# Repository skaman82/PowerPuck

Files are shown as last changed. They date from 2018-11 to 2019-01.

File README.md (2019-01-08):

# PowerPuck
I started this project because I was tired of my fatshark beeping and shutting down at 3.6 volts. I am using a 2s 18650 3500mAh pack. This means my batteries are still almost half full when this happens. I first just used a 9v stepup to boost the voltage, but then tracking the battery level was a pain. Then I came up with this solution. 

It not only lets you use your 18650 batteries up to 3v (per cell), it also adds voltage monitoring with adjustable alarms and a power on/off switch. On top of that the fan cable is now tidy and nice and the complete unit remains on the goggles the whole time while the battery is sitting in the pocket or on the belt.

The battery case has also a basic battery indicator - it gives a pretty good orientation of the battery state without hooking the battery up. 

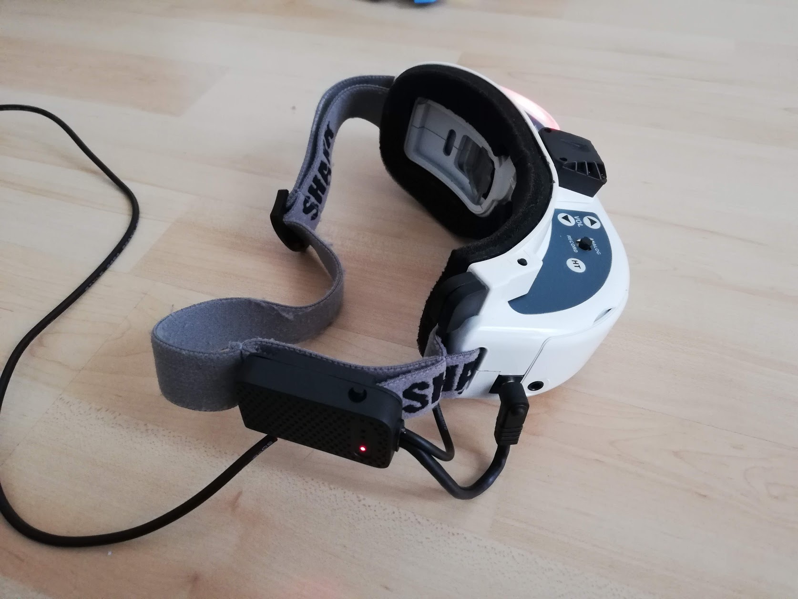
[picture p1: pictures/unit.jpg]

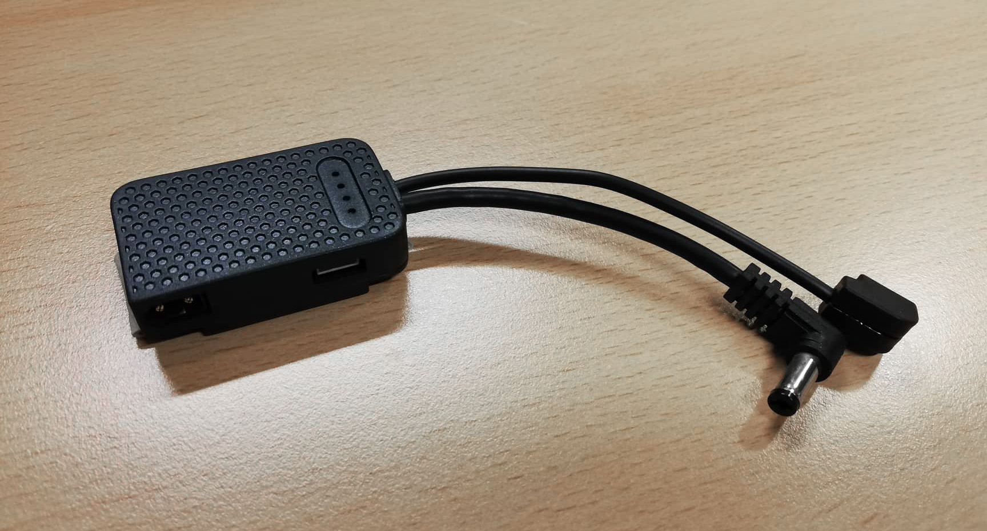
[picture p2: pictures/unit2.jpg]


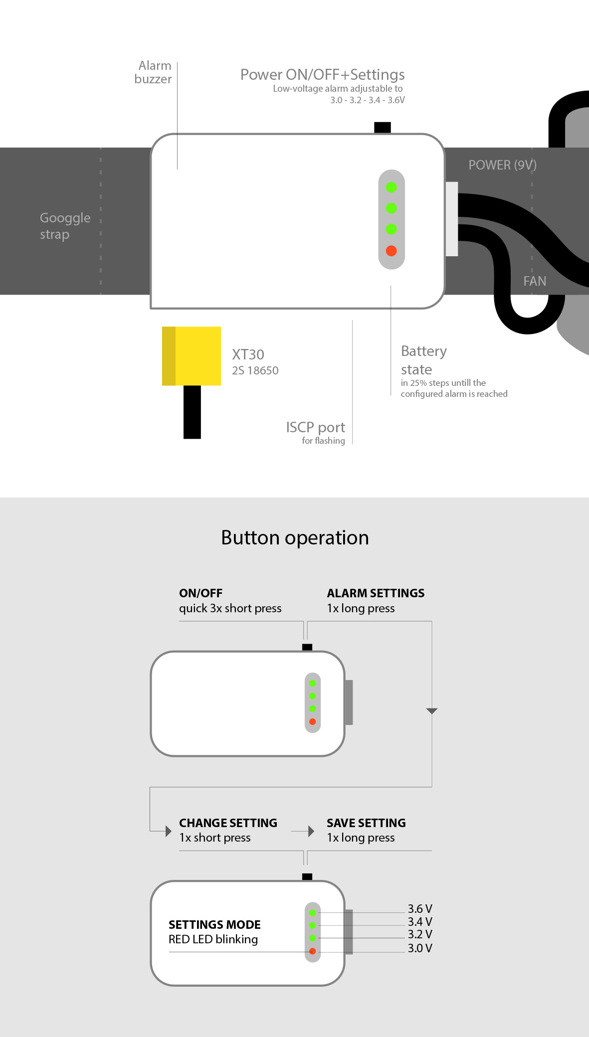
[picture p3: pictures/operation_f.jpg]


# MAIN UNIT COMPONENTS
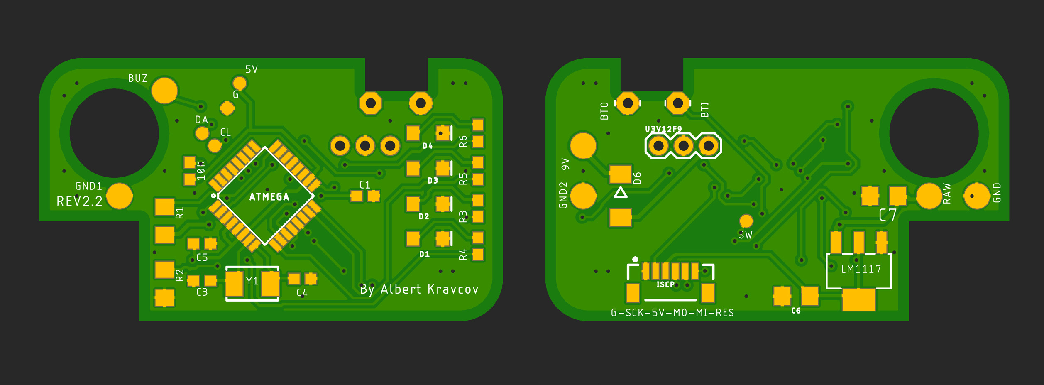
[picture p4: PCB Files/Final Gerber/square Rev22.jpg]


<b>Printed Case</b></br>
See 3D files directory</br>
or order it here:</br>
https://www.shapeways.com/product/Y7TP35MAT/powerpuck-case-front</br>
https://www.shapeways.com/product/XVMKZEAJ4/powerpuck-case-back</br>
</br></br>

<b>Order the PCB on jlcpcb.com (1mm thickness)</b></br>
See "PCB Files > Final Gerber" directory</br></br>

<b>ATMEGA382 AU</b></br>
<b>Y1: Xtal 16MHZ TXC 7A-16.000MAAJ-T</b></br>
<b>C1: 0,1uF cap 0603</b></br>
<b>C5: 100nF cap 0603</b></br>
<b>C3, C4: 18pF cap 0603 (2x)</b></br>
<b>10K 0603 Resistor</b></br>
<b>R3-R6: 330Ohm 0603 Resistor (4x)</b></br>
<b>D2-D4: GREEN LED 1206 (3x)</b></br>
<b>D1: 1x RED LED 1206</b></br>
<b>R1: 18K Resistor 1206</b></br>
<b>R2: 4,7K Resistor 1206</b></br>
<b>C6, C7: 10uF Cap 1206 (2x)</b></br>
<b>D6: Diode S1A</b></br>
<b>Pololu 9V Step-Up Voltage Regulator U3V12F9</b></br>
<b>Pololu Mini Pushbutton Power Switch SV</b></br>
<b>JST-SH Socket 6pin</b></br>
<b>9mm active Buzzer</b></br>
<b>8mm tact button</b></br>
<b>AMASS XT30 female plug</b></br>
<b>AMS1117/LM1117 regulator</b></br>
<b>Epoxy</b></br></br>

<b>ISCP USB Programmer like</b></br>
https://de.aliexpress.com/item/5-v-Micro-USB-Tiny-AVR-ISP-ATtiny44-USBTinyISP-Programmierer-Modul-F-r-Bootloader-ISP-Mikrocontroller/32925343387.html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</br></br>

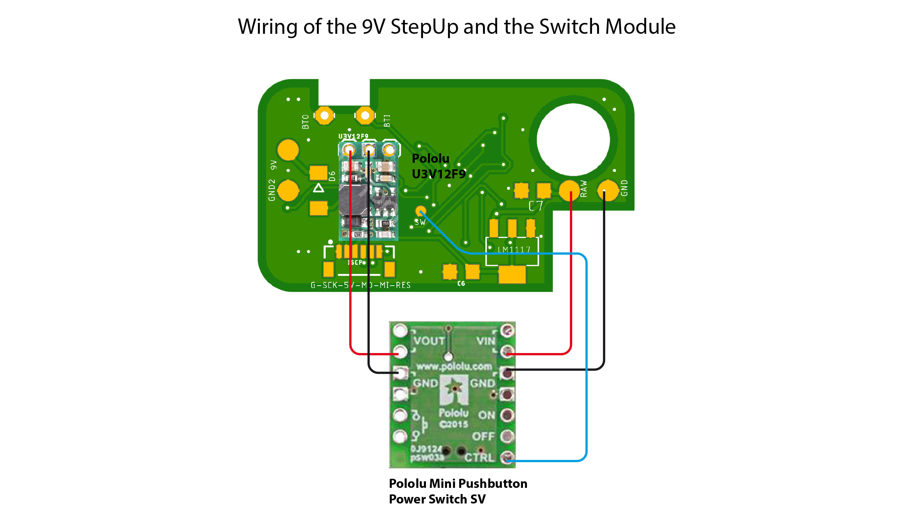
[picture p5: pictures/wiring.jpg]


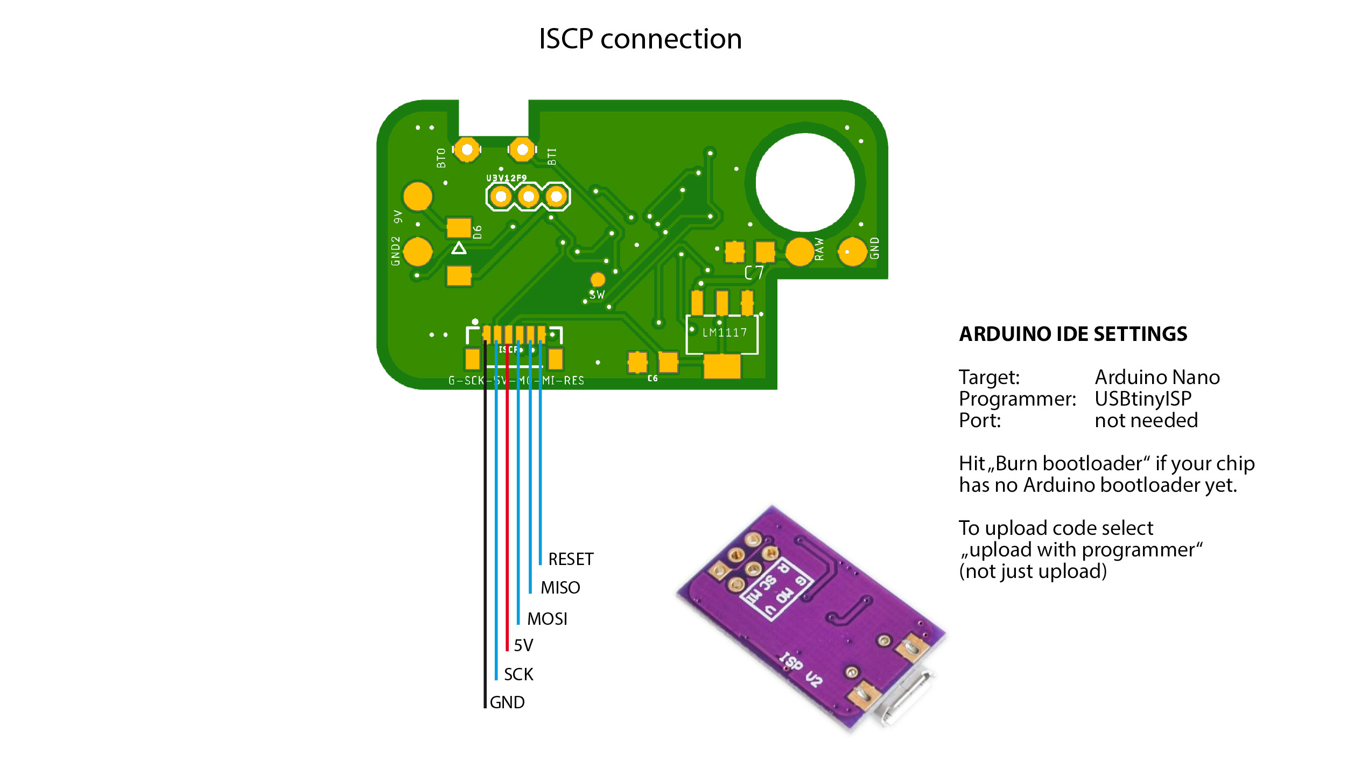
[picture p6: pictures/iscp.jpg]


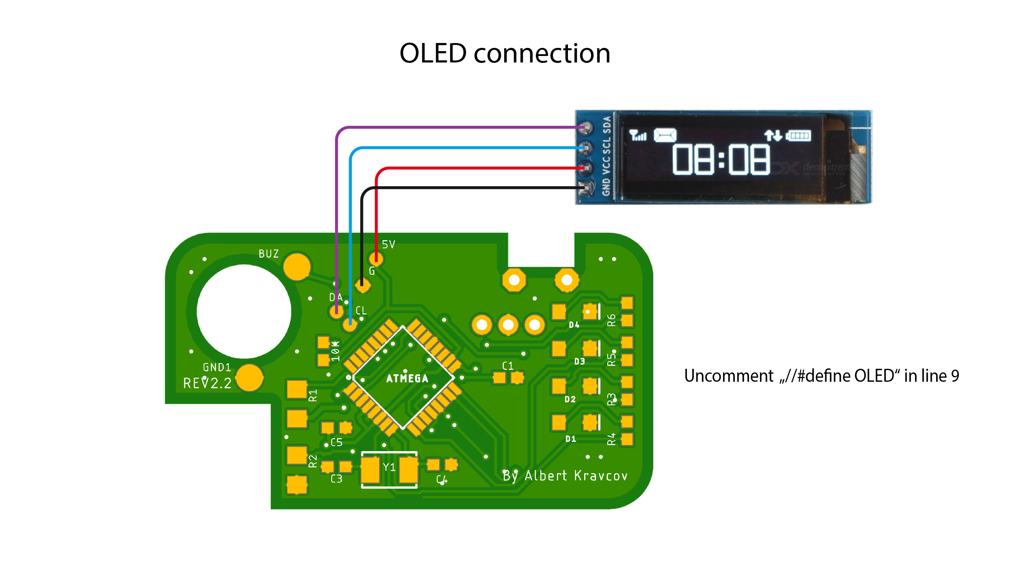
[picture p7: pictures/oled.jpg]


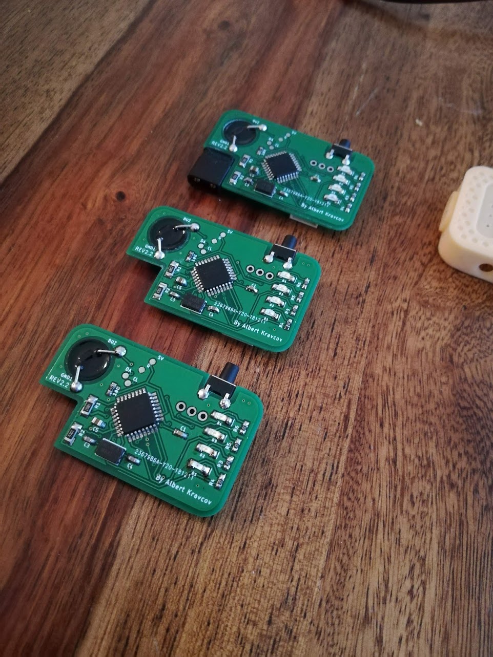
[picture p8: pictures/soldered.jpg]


# 18650 CASE COMPONENTS
<b>Printed Case</b></br>
See 3D files directory</br></br>

<b>2S Power-Indicator</b></br>
https://www.banggood.com/2S-3S-4S-5S-Lipo-Battery-Voltage-Display-Indicator-Board-Polymer-Power-Indicator-Panel-p-1095698.html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</br></br>

<b>2S BMS PCB</b></br>
https://www.aliexpress.com/item/2S-7-4V-8-4V-8A-16A-18650-Lithium-Battery-Protection-Board-Current-Li-ion-2/32851804815.html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</br></br>

<b>XT30 connectors</b></br>
https://www.banggood.com/de/Tarot-RC-Helicopter-Part-Amass-One-Pair-XT30-Non-slip-Plugs-TL2918-p-954269.html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</br></br>

<b>2S Balance plug</b></br>
https://www.banggood.com/de/Lipo-Battery-Balance-Charging-Extension-Wire-Cable-20cm-2S-3S-4S-6S-p-951866.html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
</br>
<b>Epoxy</b></br></br>

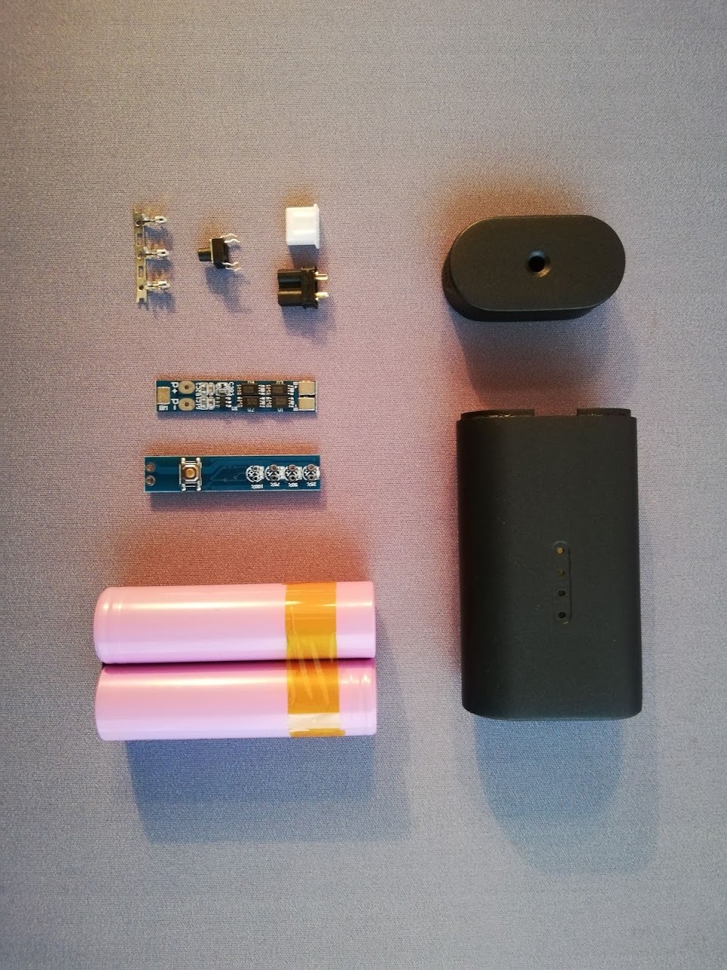
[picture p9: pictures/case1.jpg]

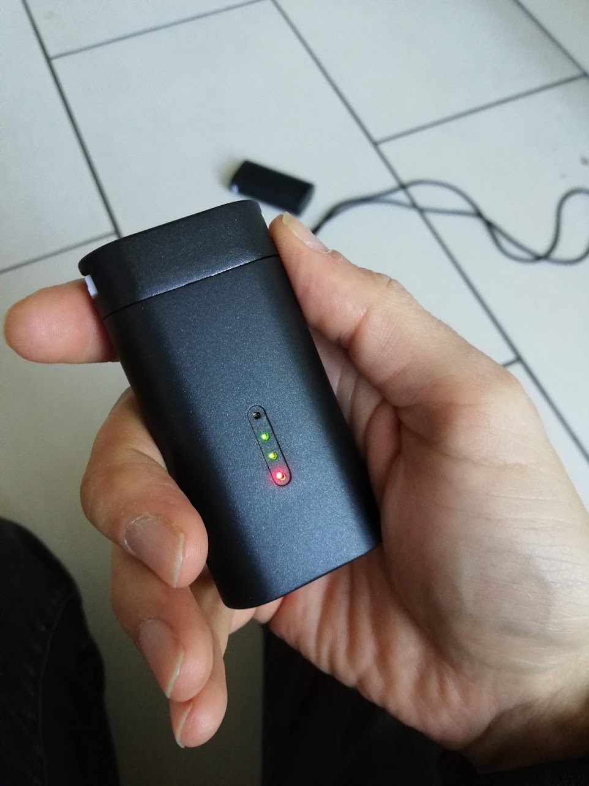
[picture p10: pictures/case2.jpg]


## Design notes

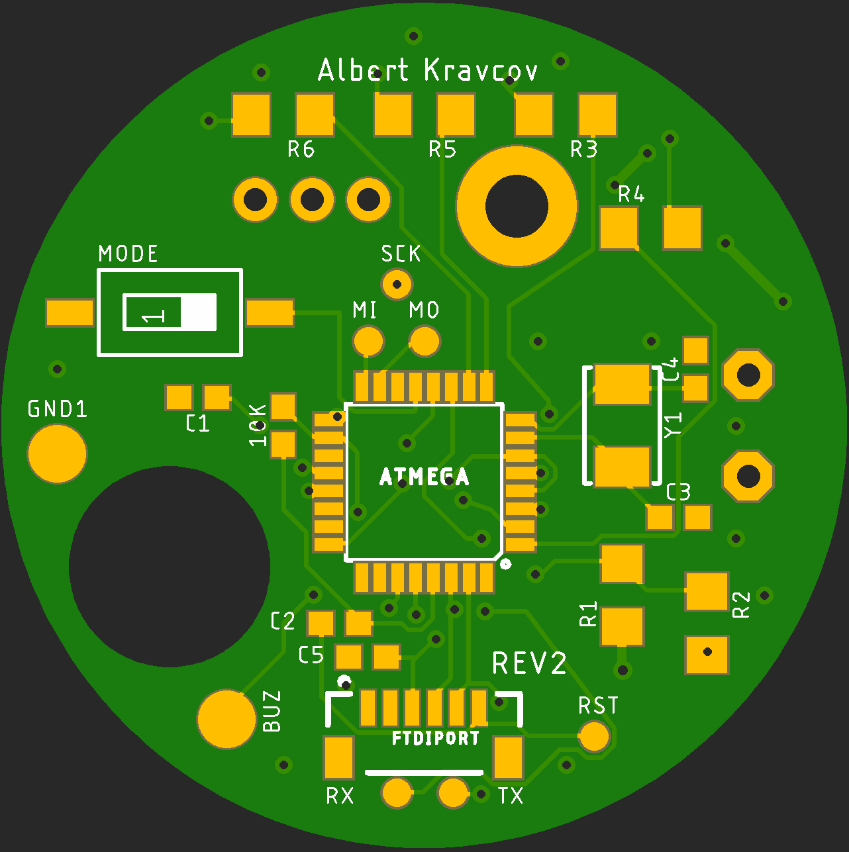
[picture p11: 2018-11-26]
3D Files/Main Unit/tex/Round Rev3.png

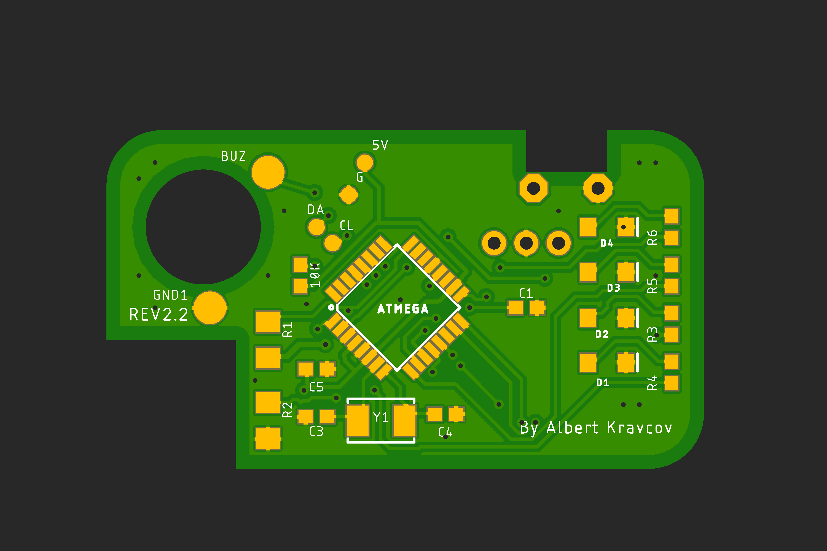
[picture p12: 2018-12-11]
PCB Files/Final Gerber/square Rev22_t.png

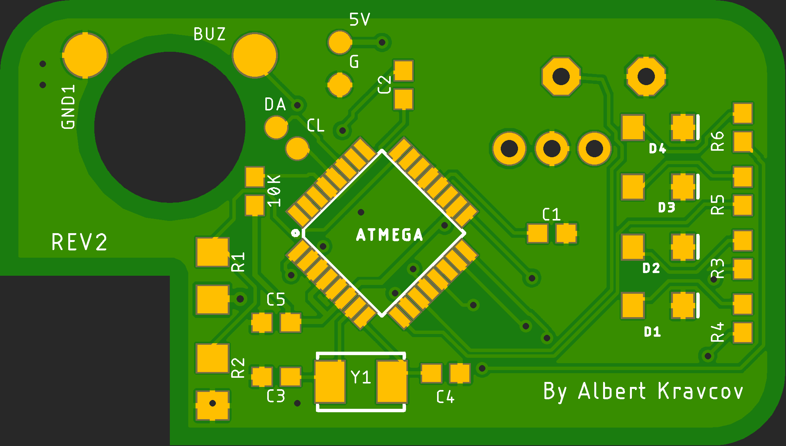
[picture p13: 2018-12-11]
3D Files/Main Unit/tex/square Rev2_top.png

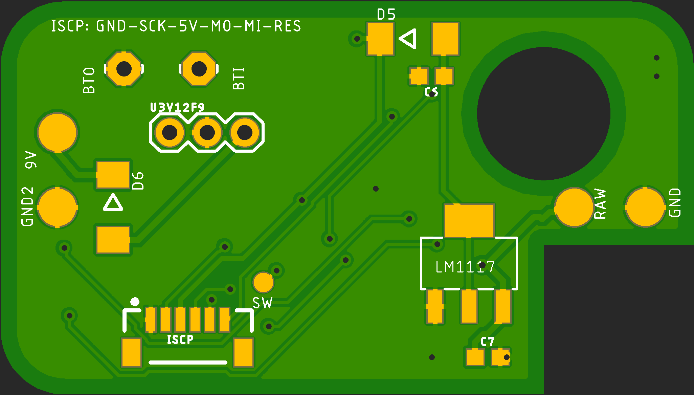
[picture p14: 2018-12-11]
3D Files/Main Unit/tex/square Rev2_bottom.png

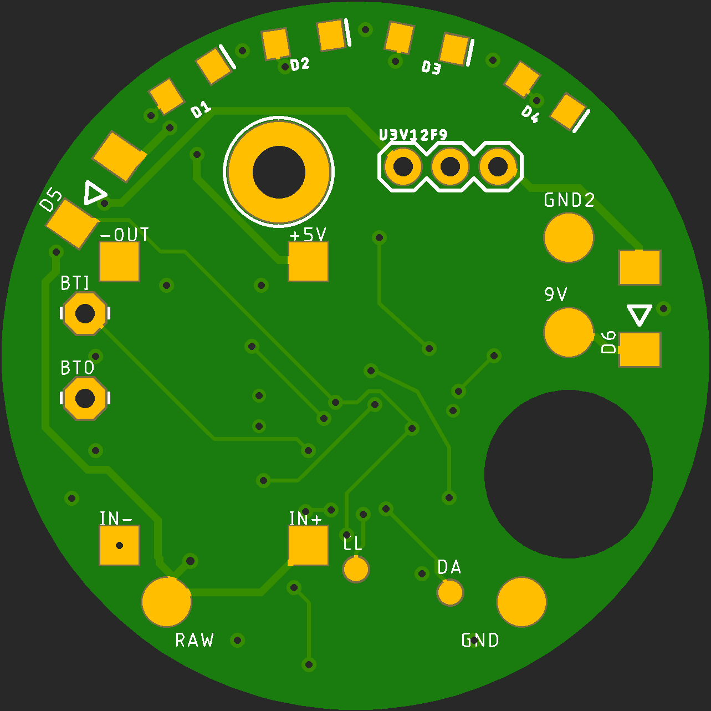
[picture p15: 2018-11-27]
3D Files/Main Unit/tex/Round Rev3_top.png

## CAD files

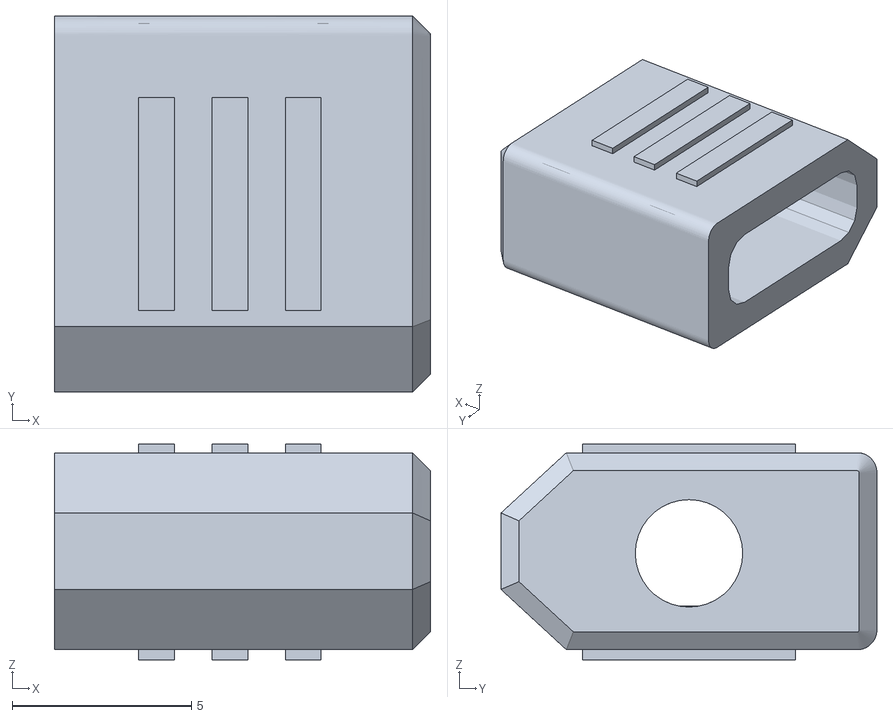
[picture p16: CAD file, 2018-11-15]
3D Files/18650 Battery Case/xt30_handle.stl
10.5 x 10.5 x 6.03

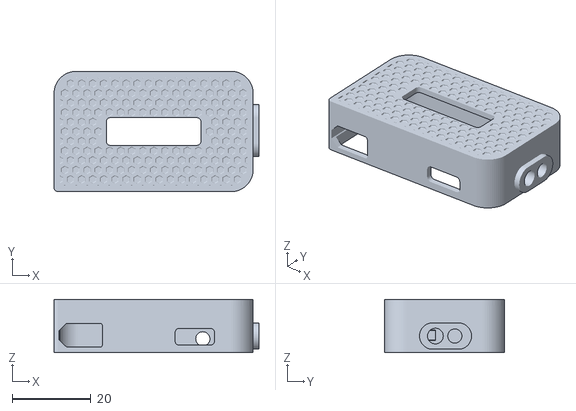
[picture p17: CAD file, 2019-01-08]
3D Files/Main Unit/case square OLED.stl
52.0 x 30.5 x 13.5

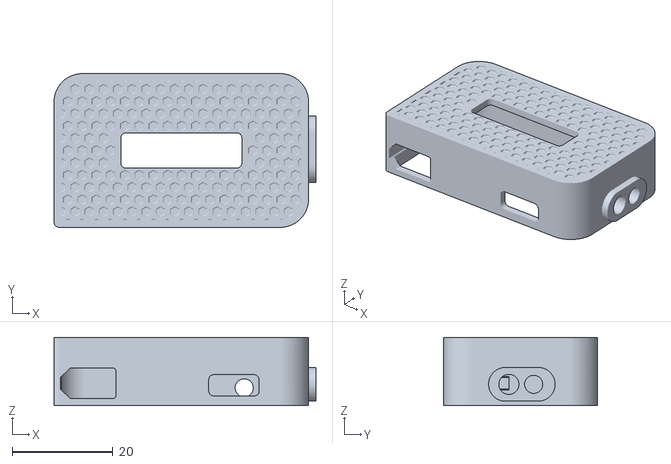
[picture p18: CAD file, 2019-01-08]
3D Files/Main Unit/STLs Final/case square OLED_top.stl
52.0 x 30.5 x 13.5

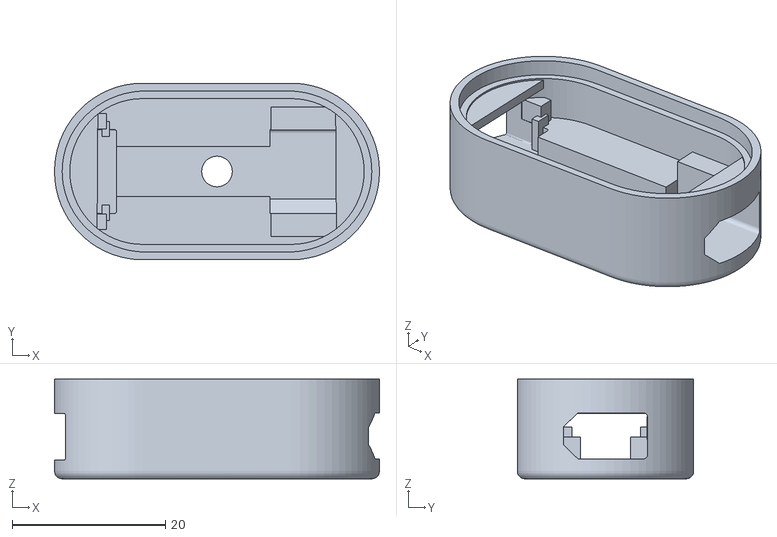
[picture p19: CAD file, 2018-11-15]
3D Files/18650 Battery Case/2S case_top.stl
42.4 x 23.0 x 13.0

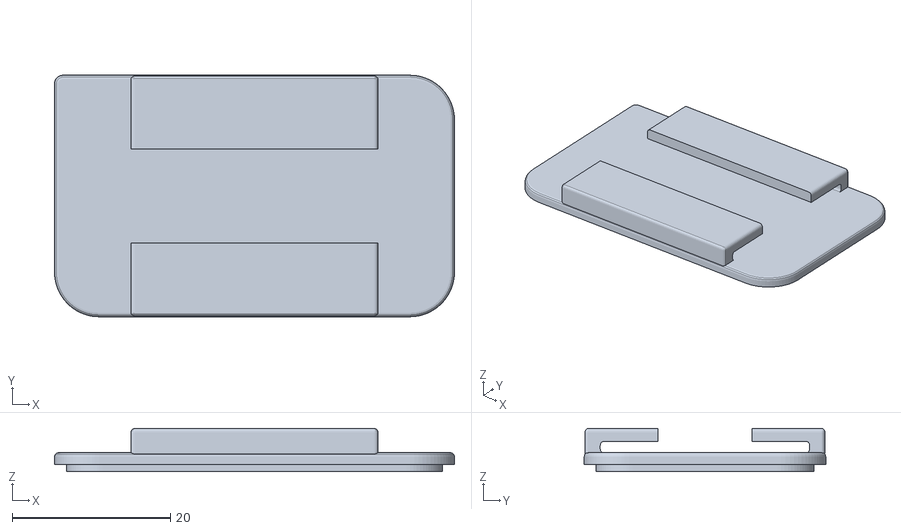
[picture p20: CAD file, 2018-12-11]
3D Files/Main Unit/case square_cover.stl
50.5 x 30.5 x 5.43

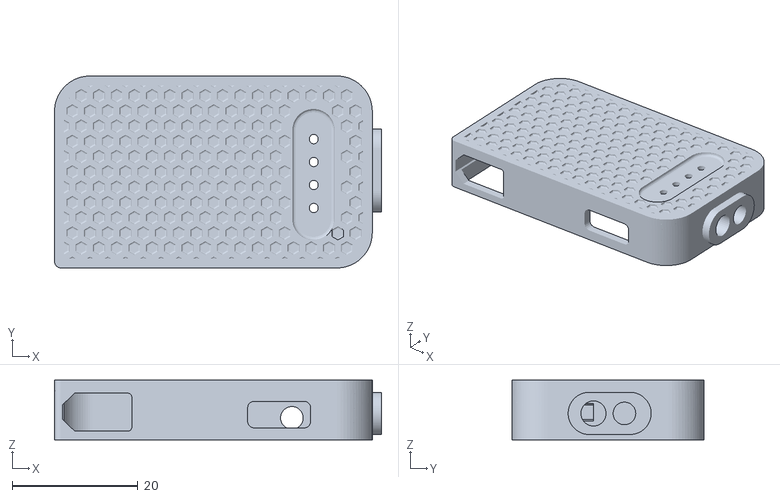
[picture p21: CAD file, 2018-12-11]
3D Files/Main Unit/STLs Final/case square_top.stl
52.0 x 30.5 x 9.50

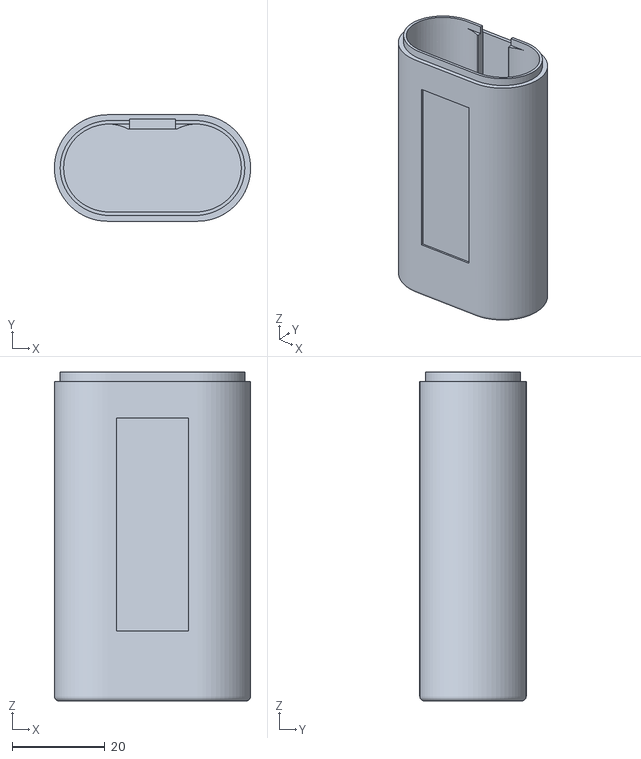
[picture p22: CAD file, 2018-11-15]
3D Files/18650 Battery Case/2S case_bottom.stl
42.4 x 23.0 x 71.0

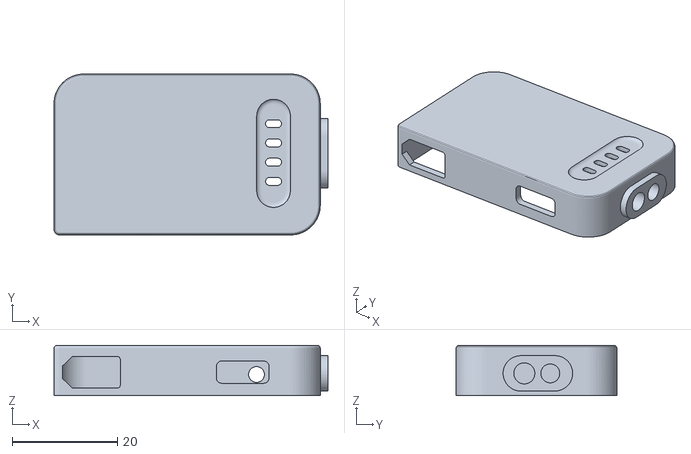
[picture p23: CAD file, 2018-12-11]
3D Files/Main Unit/case square_fixed.stl
52.0 x 30.5 x 9.50

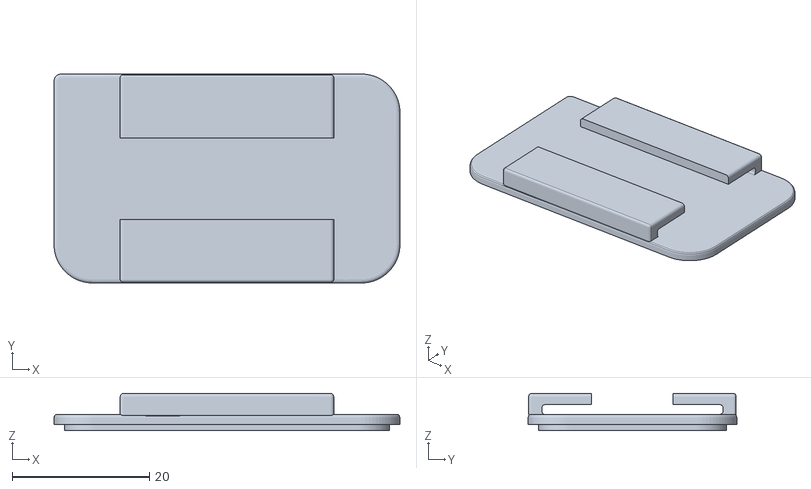
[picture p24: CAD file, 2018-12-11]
3D Files/Main Unit/STLs Final/case square_back.stl
50.5 x 30.5 x 5.43

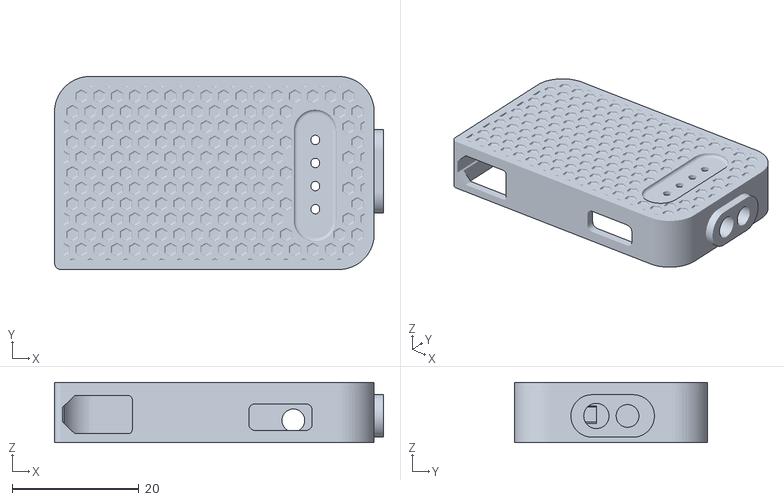
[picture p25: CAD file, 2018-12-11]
3D Files/Main Unit/case square2.stl
52.0 x 30.5 x 9.50

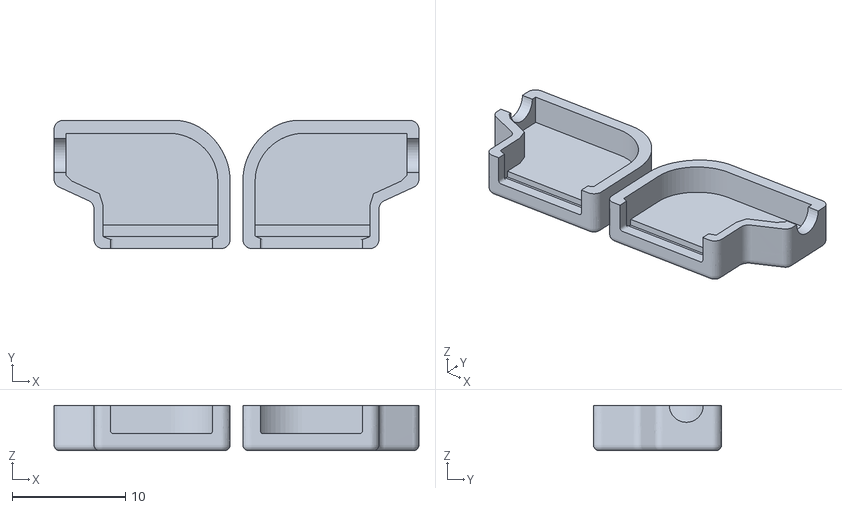
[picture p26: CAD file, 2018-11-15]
3D Files/Main Unit/STLs Final/balance_fixed.stl
32.2 x 11.3 x 4.00

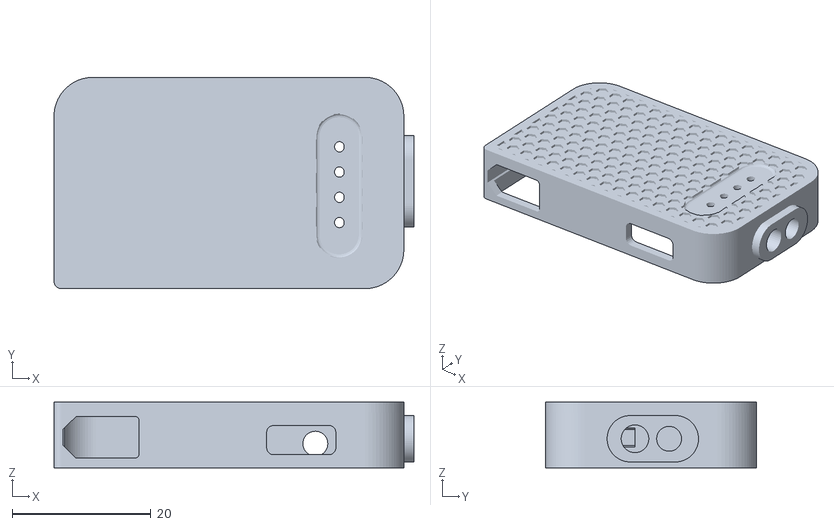
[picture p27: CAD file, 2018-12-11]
3D Files/Main Unit/case square.stl
52.0 x 30.5 x 9.50

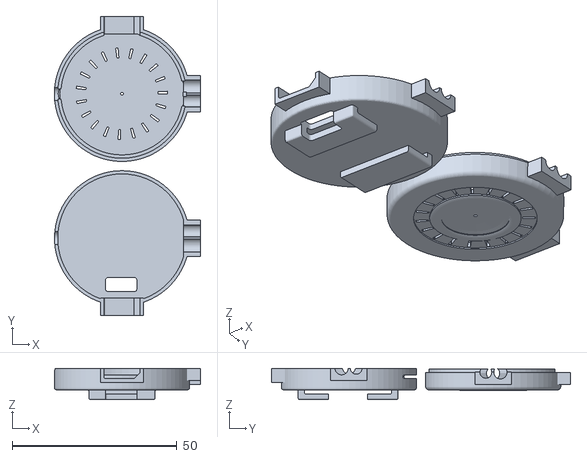
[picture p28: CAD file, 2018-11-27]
3D Files/Main Unit/Round Case.stl
44.4 x 90.8 x 9.49

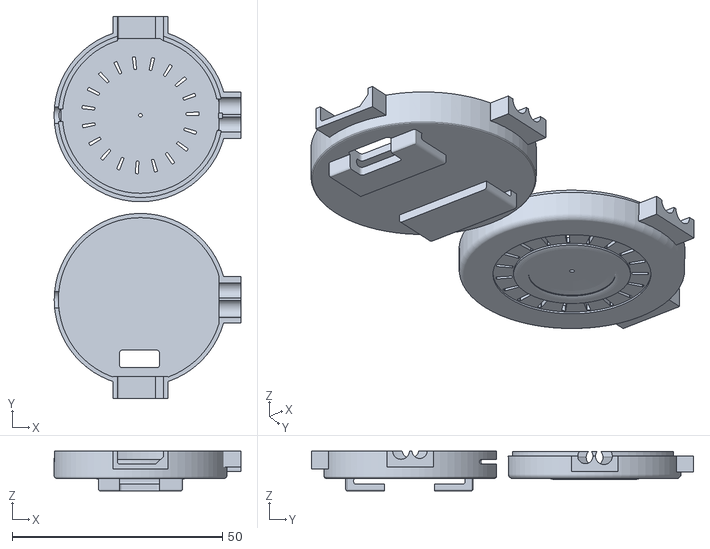
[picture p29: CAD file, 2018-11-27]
3D Files/Main Unit/Round Case_fixed.stl
44.4 x 90.8 x 9.49

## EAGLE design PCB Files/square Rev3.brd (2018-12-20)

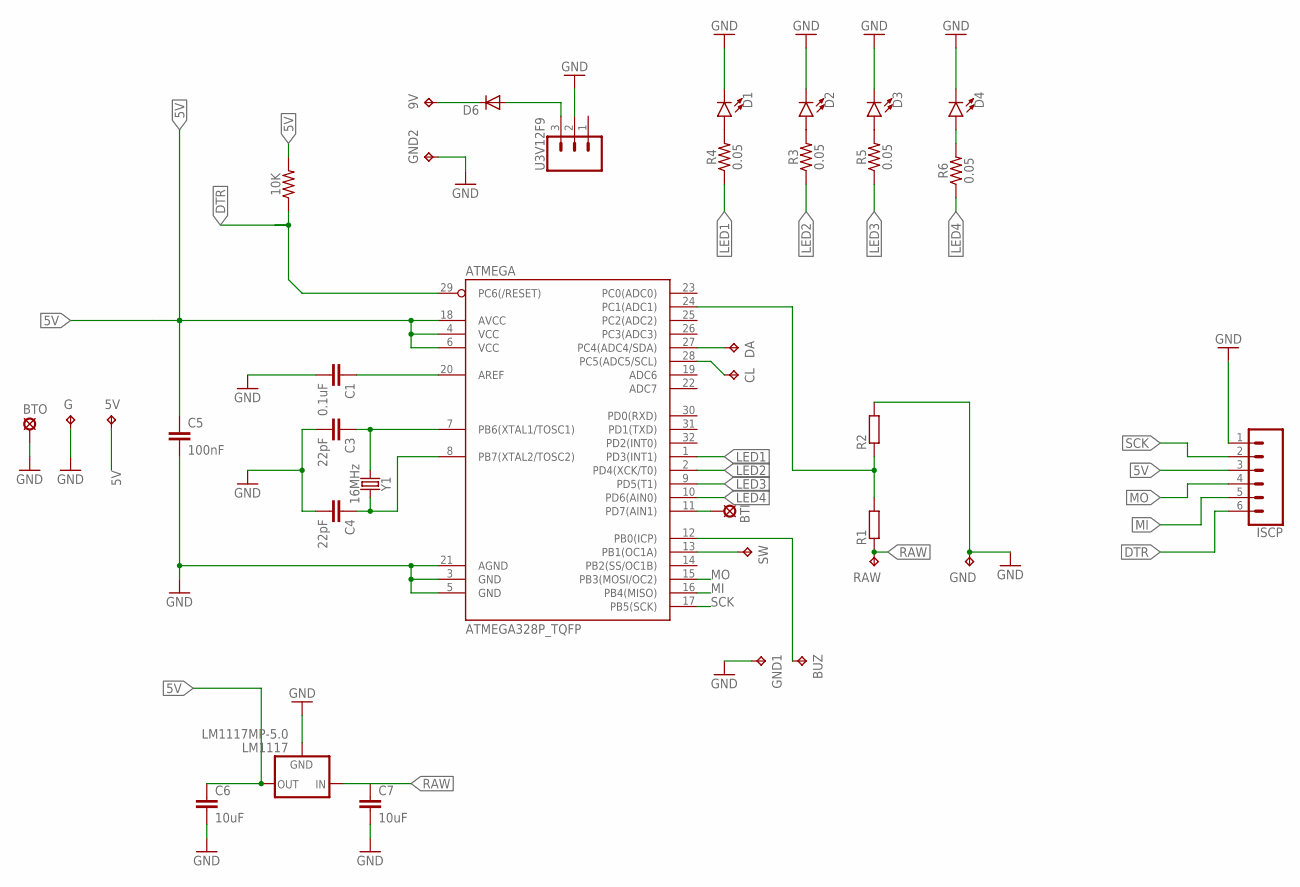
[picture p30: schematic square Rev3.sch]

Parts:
5V: TPB1,27; B1,27
9V: TPB2,54; B2,54
10K: 0.27OHM-0603-1/10W-1%; 0603
ATMEGA: ATMEGA328P_TQFP; TQFP32-08
BTI: LSP10
BTO: LSP10
BUZ: TPB2,54; B2,54
C1: 0.1uF; 0603
C3, C4: 22pF; 0603
C5: 100nF; 0603
C6: 10uF; 1206
C7: 10uF; C1206
CL: TPB1,27; B1,27
D1, D2, D3, D4: LED1206; LED-1206
D6: DIODE-SOD106A-R; SOD106A-R
DA: TPB1,27; B1,27
G: TPB1,27; B1,27
GND, GND1, GND2: TPB2,54; B2,54
ISCP: CONN_06SMD-1MM; 1X06-1MM
LM1117: LM1117MP-5.0; SOT223
R1, R2: R-EU_R1206; R1206
R3, R4, R5, R6: 0.05; 0603
RAW: TPB2,54; B2,54
SW: TPB1,27; B1,27
U3V12F9: CONN_03; 1X03
Y1: 16MHz; CRYSTAL-SMD-5X3.2-2PAD

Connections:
5V: 5V.TP, 10K.2, ATMEGA.4 (VCC), ATMEGA.6 (VCC), ATMEGA.18 (AVCC), C5.1, C6.1, ISCP.3, LM1117.2 (OUT), LM1117.4 (OUT)
9VOUT: D6.A, U3V12F9.3
AREF: ATMEGA.20 (AREF), C1.1
BUTTON: ATMEGA.11 (PD7(AIN1)), BTI.MP
BUZZER: ATMEGA.12 (PB0(ICP)), BUZ.TP
DTR: 10K.1, ATMEGA.29 (PC6(/RESET)), ISCP.6
GND: ATMEGA.3 (GND), ATMEGA.5 (GND), ATMEGA.21 (AGND), BTO.MP, C1.2, C3.2, C4.2, C5.2, C6.2, C7.2, D1.C, D2.C, D3.C, D4.C, G.TP, GND.TP, GND1.TP, GND2.TP, ISCP.1, LM1117.1 (GND), R2.2, U3V12F9.2
GREEN1: D2.A, R3.2
GREEN2: D3.A, R5.2
GREEN3: D4.A, R6.2
LED1: ATMEGA.1 (PD3(INT1)), R4.1
LED2: ATMEGA.2 (PD4(XCK/T0)), R3.1
LED3: ATMEGA.9 (PD5(T1)), R5.1
LED4: ATMEGA.10 (PD6(AIN0)), R6.1
MI: ATMEGA.16 (PB4(MISO)), ISCP.5
MO: ATMEGA.15 (PB3(MOSI/OC2)), ISCP.4
unnamed: ATMEGA.13 (PB1(OC1A)), SW.TP
unnamed: 9V.TP, D6.C
RAW: C7.1, LM1117.3 (IN), R1.1, RAW.TP
RED: D1.A, R4.2
SCK: ATMEGA.17 (PB5(SCK)), ISCP.2
SCL: ATMEGA.28 (PC5(ADC5/SCL)), CL.TP
SDA: ATMEGA.27 (PC4(ADC4/SDA)), DA.TP
VOLTSENS: ATMEGA.24 (PC1(ADC1)), R1.2, R2.1
XTAL1: ATMEGA.7 (PB6(XTAL1/TOSC1)), C3.1, Y1.P$1 (1)
XTAL2: ATMEGA.8 (PB7(XTAL2/TOSC2)), C4.1, Y1.P$2 (2)

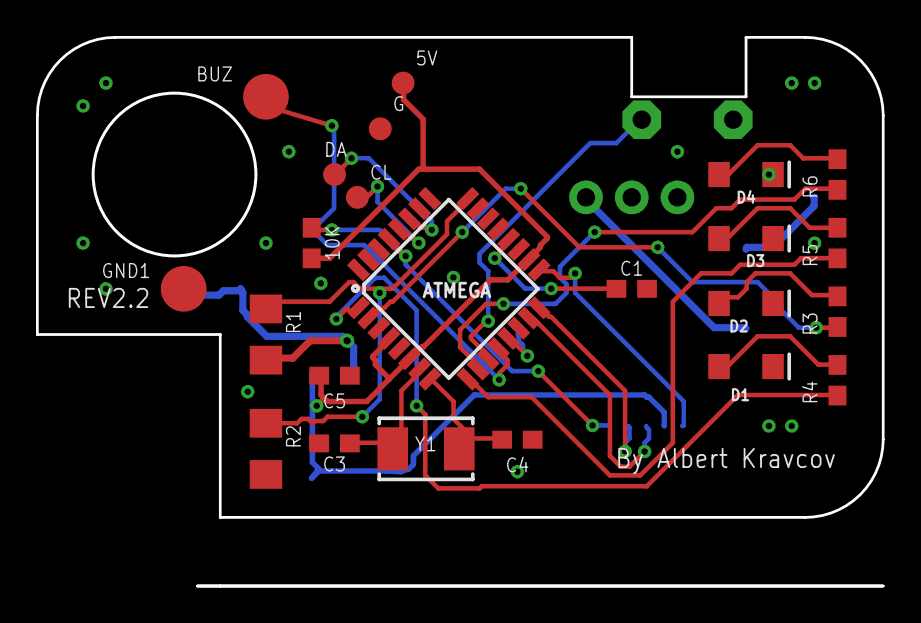
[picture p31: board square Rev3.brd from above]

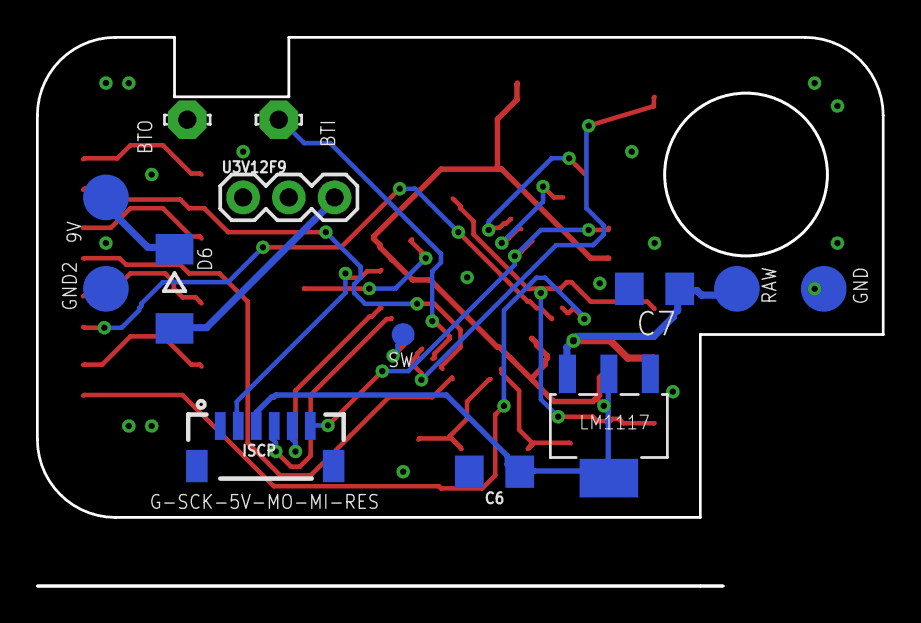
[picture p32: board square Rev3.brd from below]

Board: 2 copper layers, 47.0 x 26.7 mm, 36 parts (13 on the bottom side), 26 nets.

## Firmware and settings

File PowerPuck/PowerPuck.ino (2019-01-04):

/*
  Initial code for my PowerPuck project.
  Created by Albert Kravcov

*/
#include <EEPROM.h>

// uncomment this if you are usind an OLED screen
#define OLED

#define Voltagedetect          3.25 // Min. voltage for Detection
#define max_cellvoltage        4.25 // Max. cell voltage
#define R1                   17800  // Resistor 1
#define R2                    4700  // Resistor 2 (measured)
#define VOLT_SENS               A1  // Voltage Sensor
#define BUTTON_PIN               7  // Button
#define longpresstime         1000  // in ms
#define alarmADDR                1  // EEPROM Adress


#define NOTE_C4                 262  // C4
#define NOTE_A6                 1760 // A6

float voltage;
int32_t lipo;
float alarmvalue = 3.40;
int32_t alarmvalueEEP;
float cellvoltage;
int32_t battery_health = 4;
int pressedbut = 0;
int i_butt = 0;
int mode;
int menuselect;
unsigned long runtime = 0;
unsigned long spendtime = 0;
unsigned long healthtime = 0;
int AlarmState = LOW;
long interval = 500;
long interval2 = 1000;
int MenuState = LOW;
long menuinterval = 100;
int32_t powermode = 1;
int32_t buttoncount = 0;
unsigned long presstime = 0;

unsigned long updatetime = 0;
int8_t counter = 0;
int32_t oldvoltage = 0;
int32_t samplevoltage = 0;


#ifdef OLED 
#include "U8glib.h"
U8GLIB_SSD1306_128X32 u8g(U8G_I2C_OPT_NONE);  // I2C / TWI
#endif



void setup() {

 
  analogReference(DEFAULT);

  pinMode(3, OUTPUT); //LED red
  pinMode(4, OUTPUT); //LED green1
  pinMode(5, OUTPUT); //LED green2
  pinMode(6, OUTPUT); //LED green3
  pinMode(8, OUTPUT); //Buzzer
  pinMode(9, OUTPUT); //power
  digitalWrite(9, HIGH); //power on
  pinMode(BUTTON_PIN, INPUT_PULLUP);
  pinMode(13, OUTPUT); //ledbuidin

  Serial.begin(9600);

  alarmvalueEEP = EEPROM.read(alarmADDR);

  if (alarmvalueEEP != 0)
  {
    alarmvalue = (alarmvalueEEP / 10.0);
  }
  if (alarmvalueEEP > 250)
  {
    alarmvalue = 3.40;
  }
  else { }


  digitalWrite(8, HIGH);
  delay(100);
  digitalWrite(8, LOW);
  
  digitalWrite(3, HIGH);   // turn the LED on (HIGH is the voltage level)
  delay (100);
  digitalWrite(4, HIGH);   // turn the LED on (HIGH is the voltage level)
  delay (100);
  digitalWrite(5, HIGH);   // turn the LED on (HIGH is the voltage level)
  delay (100);
  digitalWrite(6, HIGH);   // turn the LED on (HIGH is the voltage level)
  delay (250);
  digitalWrite(6, LOW);   // turn the LED on (HIGH is the voltage level)
  delay (100);
  digitalWrite(5, LOW);   // turn the LED on (HIGH is the voltage level)
  delay (100);
  digitalWrite(4, LOW);   // turn the LED on (HIGH is the voltage level)
  delay (100);
  digitalWrite(3, LOW);   // turn the LED on (HIGH is the voltage level)
  delay (250);

 
  voltagetest();
  lipo = 2;
  

#ifdef OLED 

    if ( u8g.getMode() == U8G_MODE_R3G3B2 ) {
      u8g.setColorIndex(255);     // white
    }
    else if ( u8g.getMode() == U8G_MODE_GRAY2BIT ) {
      u8g.setColorIndex(3);         // max intensity
    }
    else if ( u8g.getMode() == U8G_MODE_BW ) {
      u8g.setColorIndex(1);         // pixel on
    }
    else if ( u8g.getMode() == U8G_MODE_HICOLOR ) {
      u8g.setHiColorByRGB(255, 255, 255);
    }

  clearOLED();
  
  #endif
}




void voltagetest()
{

  int sensorValue = analogRead(VOLT_SENS); // read the input on analog pin 0:

    unsigned long currentrunthtime = millis();
    if (currentrunthtime - updatetime >= 100) {
      updatetime = currentrunthtime;
      counter += 1;
      samplevoltage += sensorValue; 
    }
    
    if (counter >= 10) {   // if we have 10 samples            
          oldvoltage = (samplevoltage / 10);
          samplevoltage = 0;
          counter = 0;
    }
    
  voltage = oldvoltage * (6.05 / 1023.0) * ((R1 + R2) / R2); // Convert the analog reading (which goes from 0 - 1023) to a voltage, considering the voltage divider:
  // use 6.00 for direct lipo and 6.05 for packs with bms and extension cable

  cellvoltage = voltage / 2;

  float cellfull = (max_cellvoltage) - (alarmvalue); //determine 100% of travel scale
  float cellstate = (max_cellvoltage) - (cellvoltage); //determine the actual cell delta value
  float battery_state = 100 - (((cellstate) * 100) / (cellfull)); //determine cell charge left in percent

  if (battery_state >= 75)
  {
    unsigned long currenthealthtime = millis();

    if ((currenthealthtime - healthtime >= interval2) && (battery_state >= 75)) {
      healthtime = currenthealthtime;

      battery_health = 4;
    }
  }
  else if (battery_state >= 50 && battery_state < 75)
  {
    unsigned long currenthealthtime = millis();

    if ((currenthealthtime - healthtime >= interval2) && (battery_state >= 50 && battery_state < 75)) {
      healthtime = currenthealthtime;

      battery_health = 3;
    }
  }
  else if (battery_state >= 25 && battery_state < 50)
  {
    unsigned long currenthealthtime = millis();

    if ((currenthealthtime - healthtime >= interval2) && (battery_state >= 25 && battery_state < 50)) {
      healthtime = currenthealthtime;

      battery_health = 2;
    }
  }
  else if (battery_state >5 && battery_state < 25)
  {
    unsigned long currenthealthtime = millis();

    if ((currenthealthtime - healthtime >= interval2) && (battery_state >= 5 && battery_state < 25)) {
      healthtime = currenthealthtime;

      battery_health = 1;
    }
  }
  else if (battery_state >= 5)
  {
    unsigned long currenthealthtime = millis();

    if ((currenthealthtime - healthtime >= interval2) && (battery_state >= 0)) {
      healthtime = currenthealthtime;

      battery_health = 0;
    }
  }
  else {
    battery_health = 0;

  }
}



byte buttoncheck()
{
  int i_butt = 0;
  byte buttonz = 0;
  if (digitalRead(BUTTON_PIN) != 1)
  {
    while (digitalRead(BUTTON_PIN) != 1)
    {
      delay(2);
      i_butt++;
    }
    buttonz = 1;
    Serial.print(" button short");
    digitalWrite(8, HIGH);
    delay(10);
    digitalWrite(8, LOW);

    if (i_butt > (longpresstime / 2))
    {
      buttonz += 1;
      Serial.print(" button long");
      digitalWrite(8, HIGH);
      delay(200);
    }

  }
  else { }


  pressedbut = buttonz;
  return buttonz;
}

void modecheck () {

  if (pressedbut == 1) {
    const long buttontimer = millis();
    if (buttontimer - presstime > 1500) {
      buttoncount = 0;
      presstime = buttontimer;
    }
    else {
      buttoncount += 1;
    }

    if  (buttoncount == 2) {
      if (menuselect != 1) {
        if (powermode == 1) {
          Serial.print(" button power");
          digitalWrite(9, LOW); // shutdown
          tone(8, NOTE_A6, 200);
          delay(500);
          tone(8, NOTE_C4, 500);
          
          #ifdef OLED 
          clearOLED();
          #endif
          
          powermode = 0;
        }
        else {
          digitalWrite(9, HIGH); // turn on
          delay(500);
          digitalWrite(8, HIGH);
          delay(100);
          digitalWrite(8, LOW);
          powermode = 1;
        }
      }
      else {
      }
    }
  }
}




void loop() {

#ifdef OLED 
    u8g.firstPage();
    do {
    
       u8g.setFont(u8g_font_helvR14r);
       u8g.setPrintPos(5, 26);
       u8g.print(voltage);
       u8g.print("v");

      
       u8g.drawFrame(59,9,64,22);
       u8g.drawBox(122,16,4,8);

       if (battery_health == 4) {
       u8g.drawBox(62,12,13,16); //25%
       u8g.drawBox(77,12,13,16); //50%
       u8g.drawBox(92,12,13,16); //75%
       u8g.drawBox(107,12,13,16); //100%
       }
       else if (battery_health == 3) {
       u8g.drawBox(62,12,13,16); //25%
       u8g.drawBox(77,12,13,16); //50%
       u8g.drawBox(92,12,13,16); //75%
       }
        else if (battery_health == 2) {
       u8g.drawBox(62,12,13,16); //25%
       u8g.drawBox(77,12,13,16); //50%

       }
        else if (battery_health == 1) {
       u8g.drawBox(62,12,13,16); //25%

       }
       else if (battery_health == 0) {

       
       u8g.setFont(u8g_font_lucasfont_alternater);
       u8g.setPrintPos(70, 23);
       u8g.print("LOW BAT.");
       
       }
       
#endif

    modecheck();
    buttoncheck();
    voltagetest();

    alarms();

    if (battery_health == 0) {
      digitalWrite(13, HIGH);
    }
    else {
      digitalWrite(13, LOW);
    }

    if (battery_health == 4)
    {
      digitalWrite(3, HIGH);
      digitalWrite(4, HIGH);
      digitalWrite(5, HIGH);
      digitalWrite(6, HIGH);
      AlarmState = LOW;
    }
    else if (battery_health == 3)
    {
      digitalWrite(3, HIGH);
      digitalWrite(4, HIGH);
      digitalWrite(5, HIGH);
      digitalWrite(6, LOW);
      AlarmState = LOW;
    }
    else if (battery_health == 2)
    {
      digitalWrite(3, HIGH);
      digitalWrite(4, HIGH);
      digitalWrite(5, LOW);
      digitalWrite(6, LOW);
      AlarmState = LOW;
    }
    else if (battery_health == 1)
    {
      digitalWrite(3, HIGH);
      digitalWrite(4, LOW);
      digitalWrite(5, LOW);
      digitalWrite(6, LOW);
      AlarmState = LOW;
    }

    else if (battery_health == 0)
    {
      if (AlarmState == LOW)
      {
        digitalWrite(3, LOW);
      }
      digitalWrite(4, LOW);
      digitalWrite(5, LOW);
      digitalWrite(6, LOW);
    }
    else {
    }


    if (powermode == 0) {
      unsigned long currentruntime = millis();
      if (currentruntime - runtime >= 3000) {
        runtime = currentruntime;

        shadowmode();
      }
    }

    if (pressedbut == 2)
    {
      menuselect = 1;
      menu();
    }

    Serial.println();

 #ifdef OLED 
 } while ( u8g.nextPage() );
#endif
}


#ifdef OLED 
  void clearOLED() {

    u8g.firstPage();
    do {
    } while ( u8g.nextPage() );

  }
#endif

void shadowmode() {

  while (powermode == 0) {
    
    modecheck();
    buttoncheck();
    voltagetest();
    alarms();


    if (AlarmState == LOW) {
      digitalWrite(3, LOW);
    }
    digitalWrite(4, LOW);
    digitalWrite(5, LOW);
    digitalWrite(6, LOW);


    if (pressedbut == 2)
    {
      menuselect = 1;
      #ifdef OLED 
      clearOLED();
      #endif
      menu();
    }

    if (powermode == 1)
    {
      return;
    }

  }
}


void alarms() {

  if (battery_health == 0)
  {
    //Buzzer Stuff
    unsigned long currenttime = millis();


    if (currenttime - spendtime >= interval) {
      spendtime = currenttime;

      if (AlarmState == LOW) {
        AlarmState = HIGH;
      }
      else {
        AlarmState = LOW;
      }

      digitalWrite(8, AlarmState);
      digitalWrite(3, AlarmState);


    }
  }
  else {
    digitalWrite(8, LOW);
  }
}

void menu() {
  while (menuselect == 1) {

    // Serial.print(alarmvalue);
    // Serial.println();
 #ifdef OLED 
  
  u8g.firstPage();
    do
        {
        u8g.setFont(u8g_font_lucasfont_alternater);
        u8g.setPrintPos(5, 17);
        u8g.print("ALARM");
        u8g.setPrintPos(5, 28);
        u8g.print("SETTING");
        
        u8g.setFont(u8g_font_helvR14r);
        u8g.setPrintPos(58, 26);
        u8g.print("> ");
        u8g.print(alarmvalue);
        u8g.print("v");
        }
        while (u8g.nextPage());
 #endif
    
    buttoncheck();
    digitalWrite(8, LOW);
    unsigned long currenttime = millis();

    if (currenttime - spendtime >= menuinterval) {
      spendtime = currenttime;

      if (MenuState == LOW)
        MenuState = HIGH;
      else
        MenuState = LOW;

      digitalWrite(3, MenuState);
    }

    if (pressedbut == 2)
    {

      EEPROM.write(alarmADDR, alarmvalueEEP);
      menuselect = 0;
      return;
    }


    if (alarmvalue == 3.00)
    {
      if (pressedbut == 1)
      { alarmvalue = 3.20;
        alarmvalueEEP = alarmvalue * 10.0;
      }
      digitalWrite(4, LOW);
      digitalWrite(5, LOW);
      digitalWrite(6, LOW);


    }
    else if (alarmvalue == 3.20)
    {
      if (pressedbut == 1)
      { alarmvalue = 3.40;
        alarmvalueEEP = alarmvalue * 10.0;
      }
      digitalWrite(4, HIGH);
      digitalWrite(5, LOW);
      digitalWrite(6, LOW);

    }
    else if (alarmvalue == 3.40)
    {
      if (pressedbut == 1) {
        alarmvalue = 3.60;
        alarmvalueEEP = alarmvalue * 10.0;
      }
      digitalWrite(4, HIGH);
      digitalWrite(5, HIGH);
      digitalWrite(6, LOW);

    }
    else if (alarmvalue == 3.60)
    {
      if (pressedbut == 1) {
        alarmvalue = 3.00;
        alarmvalueEEP = alarmvalue * 10.0;
      }
      digitalWrite(4, HIGH);
      digitalWrite(5, HIGH);
      digitalWrite(6, HIGH);

    }
  }

}

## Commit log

2018-11-15 18650 Case STL files
    [2S case_bottom.stl, 2S case_top.stl, xt30_handle.stl]
2018-11-15 PCB Files
    [Round.brd, Round.sch, balance_fixed.stl]
2018-11-23 PCB rev3
    [Round Rev2.brd, Round Rev2.sch, Round Rev3.brd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]
2018-11-26 deadband for voltage change
2018-11-26 2nd stage filter
2018-11-26 BEC PCB and first 3D work on the Case
    [Round Case.stl, Round Case_fixed.stl, powerboard.brd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]
2018-11-27 some 3d work
    [Round Case.stl, Round Case_fixed.stl]
2018-11-29 new form factor
    [square Rev1.brd, square Rev1.sch]
2018-11-29 some pcb adjustments
    [square Rev1.brd]
2018-11-29 another pcb version
    [square Rev2.brd, square Rev2.sch]
2018-11-29 Minor PCB update
    [square Rev2.brd, square Rev2.sch]
2018-11-29 small fix
    [square Rev2.brd]
2018-12-11 File update
    [Round Rev3.brd, Round Rev3.sch, balance_fixed.stl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]
2018-12-20 PCB updates
    [square Rev3.brd, square Rev3.sch]
2019-01-04 voltage readout improvements
2019-01-08 OLED case version
    [case square OLED.stl, case square OLED_top.stl]

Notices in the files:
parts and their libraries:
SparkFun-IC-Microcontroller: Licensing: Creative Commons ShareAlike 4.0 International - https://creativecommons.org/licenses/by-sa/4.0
